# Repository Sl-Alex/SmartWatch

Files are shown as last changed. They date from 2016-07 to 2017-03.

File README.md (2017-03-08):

# General description
This project aims to create an open-source smartwatch with the following functionality:
- 1.3" OLED display (bright enough to work in outdoor conditions)
- BLE module (HM-10), pin-to-pin compatibility with well-known HC-06
- small vibration motor (SMS/Call notifications and so on)
- STM32F103CBT6 microcontroller.
- Big external SPI flash memory (M25P40), SW OTA update and a lot of images can be stored there.
- BMC150 accelerometer/compass (can recognize double tap on the screen).
- BMP180 barometer/thermometer (just because there is a plenty of space).
- 320mAh battery allowing up to 3 weeks standby time (with BLE active).
- PCB size: 37*25, complete assembled height should be about 10mm.
- 3D models for all parts are in my [KiCAD_libs](https://github.com/Sl-Alex/KiCAD_libs) repository, case will be available a bit later, so the whole project can be easily reproduced.

# Hardware
Both schematic and PCB were created with KiCAD. KiCAD project is located in the PCB subfolder. Project uses components from my [KiCAD_libs](https://github.com/Sl-Alex/KiCAD_libs) repository.<br />
**Status**: Finished. PCB is assembled, all HW features are tested and work as expected. Standby time seems to be about 3 weeks (with BLE active).

# Software
Project is created in [EmBitz](https://www.embitz.org/)<br />
**Status**: Can be used on a daily basis with some basic functionality (automatic date/time synchronization, SMS reception). Feel free to submit patches, create or discuss issues [here](https://github.com/Sl-Alex/SmartWatch/issues).<br />

# Licensing
The whole project is available under GPL v3 license (see [LICENSE](LICENSE) file), except of files, which clearly mention other license type in the file header.

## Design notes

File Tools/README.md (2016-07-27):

# Tools for image production
## Flash Packer
This tool packs resource files in a single binary file, which can be directly downloaded into the external SPI flash.
Here is an example set of files:
- 000.txt (FW update version, ASCII text representing FW revision, for example "150")
- 001.bin (FW update itself)
- 002_FONT_SMALL.txt (all symbols for the FONT_SMALL in UCS-2LE charset)
- 002_FONT_SMALL.pbm (single image containing all symbols from FONT_SMALL in the same order like in *.txt file). PBM P4 format is used. Image has white background and black pixels. First column contains one black pixel at the font baseline. First row contain black pixels between symbols.
- 003.pbm (Image in PBM P4 format)
All necessary attributes will be calculated automatically.

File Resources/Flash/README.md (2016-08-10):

# Firmware resources
This folder contains all resources, which can be used by the firmware.
all resources should have proper naming, like NNN*.(bin|pbm|txt)
For example, 000_version.bin or 001_update.bin
3-digit number is mandatory and should match to the numbers defined in SmHwStorageIndices enumeration
(sm_hw_storage.h). Numbering starts from 000, and it is not allowed to skip some numbers.
When all resources are created, you can run flash_packer and it will produce update.bin file in this folder.
This file can be written directly to external flash using BLE connection or manually via any SPI flash adapter.

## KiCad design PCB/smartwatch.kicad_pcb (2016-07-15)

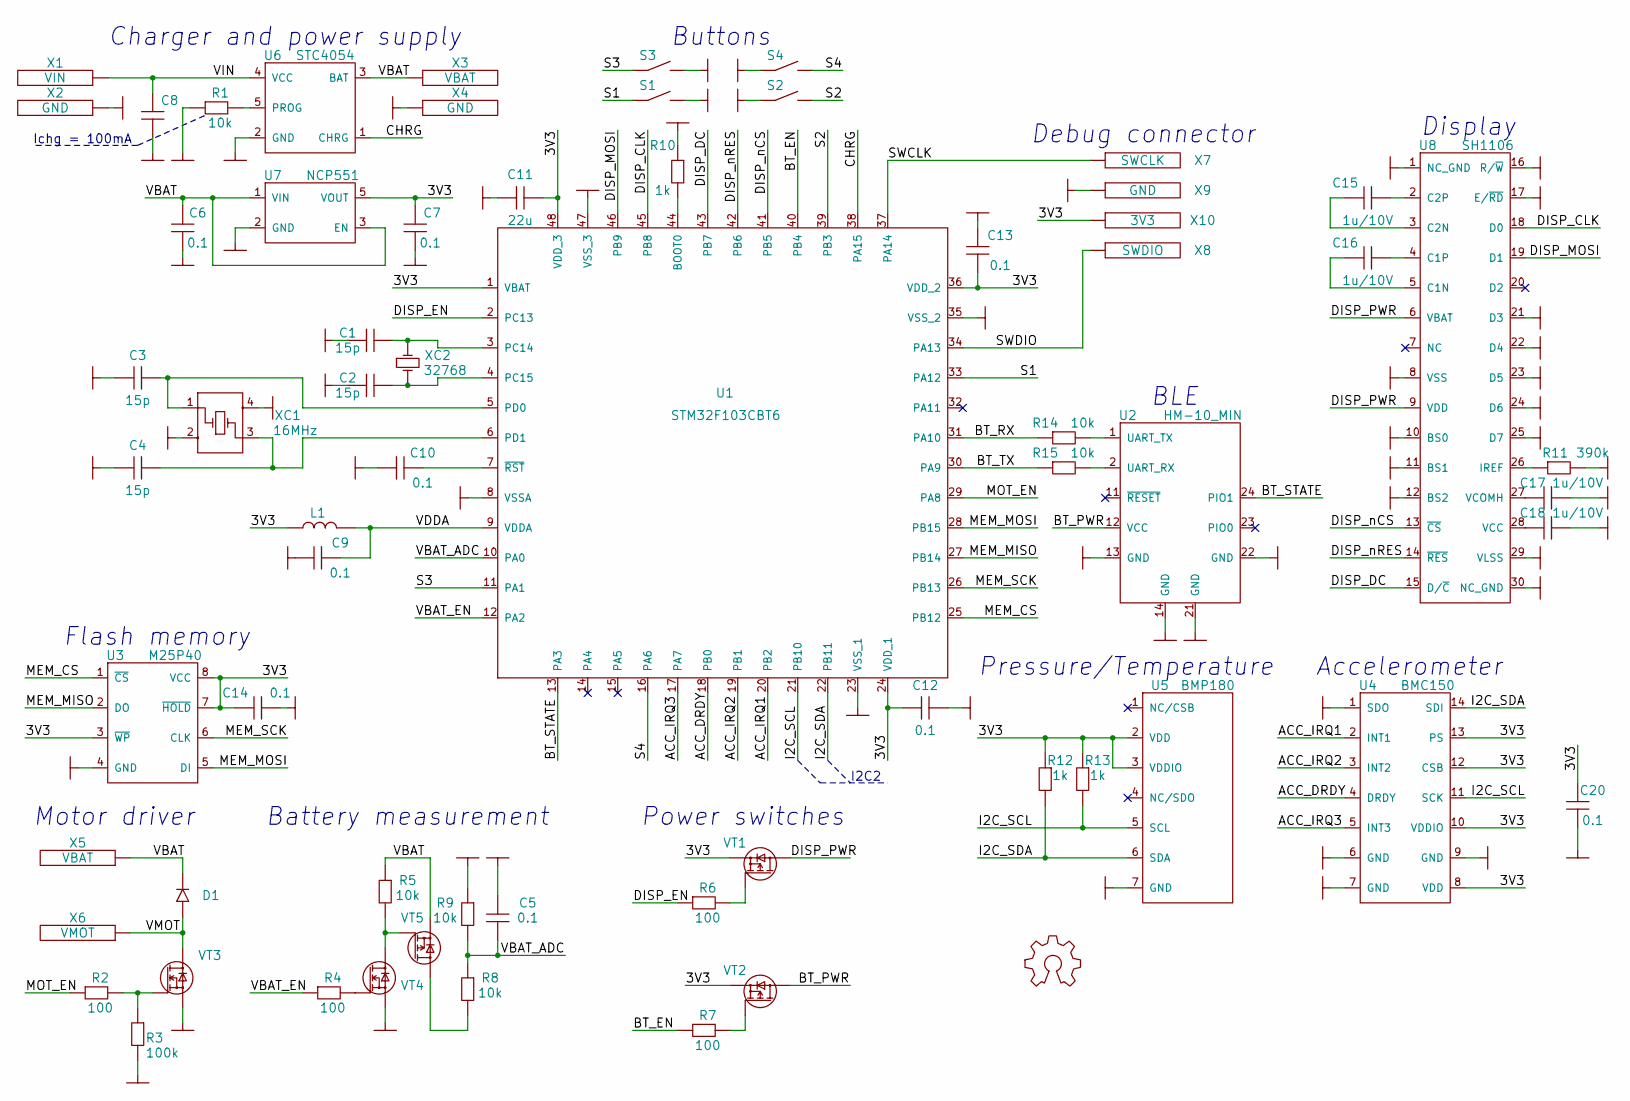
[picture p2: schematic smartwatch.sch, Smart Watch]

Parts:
C1, C2, C3, C4: 15p; 0402_C
C5, C6, C7, C9, C10, C12, C13, C14, C20: 0.1; 0402_C
C8: capacitor; 0402_C
C11: 22u; 0603_C
C15, C16, C17, C18: 1u/10V; 0603_C
D1: diode; SOD523
L1: inductor; 0603_L
LG?1: LOGO; OSHW
R1, R5, R8, R9, R14, R15: 10k; 0402_R
R2, R4, R6, R7: 100; 0402_R
R3: 100k; 0402_R
R10, R12, R13: 1k; 0402_R
R11: 390k; 0402_R
S1, S2, S3, S4: button_NO; B3U3000P
U1: STM32F103CBT6; LQFP48
U2: HM-10_MIN
U3: M25P40; SO8
U4: BMC150; LGA14
U5: BMP180; LGA7
U6: STC4054; SOT23-5
U7: NCP551; SOT23-5
U8: SH1106; UG-2864HSWEG01
VT1, VT2, VT5: MOSFET_P_DGS; PQFN2x2
VT3, VT4: MOSFET_N_DGS; PQFN2x2
X1: VIN; SLD_POINT
X2, X4, X9: GND; SLD_POINT
X3, X5: VBAT; SLD_POINT
X6: VMOT; SLD_POINT
X7: SWCLK; SLD_POINT
X8: SWDIO; SLD_POINT
X10: 3V3; SLD_POINT
XC1: 16MHz; SMD_3225
XC2: 32768; SMD_3215

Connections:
/3V3: C7.2, C11.1, C12.1, C13.1, C14.2, C20.2, L1.1, R12.1, R13.1, U1.1 (VBAT), U1.24 (VDD_1), U1.36 (VDD_2), U1.48 (VDD_3), U3.3 (~WP), U3.7 (~HOLD), U3.8 (VCC), U4.8 (VDD), U4.10 (VDDIO), U4.12 (CSB), U4.13 (PS), U5.2 (VDD), U5.3 (VDDIO), U7.5 (VOUT), VT1.3 (S), VT2.3 (S), X10.1
/ACC_DRDY: U1.18 (PB0), U4.4 (DRDY)
/ACC_IRQ1: U1.20 (PB2), U4.2 (INT1)
/ACC_IRQ2: U1.19 (PB1), U4.3 (INT2)
/ACC_IRQ3: U1.17 (PA7), U4.5 (INT3)
/BT_EN: R7.1, U1.40 (PB4)
/BT_PWR: U2.12 (VCC), VT2.1 (D)
/BT_RX: R14.1, U1.31 (PA10)
/BT_STATE: U1.13 (PA3), U2.24 (PIO1)
/BT_TX: R15.1, U1.30 (PA9)
/CHRG: U1.38 (PA15), U6.1 (CHRG)
/DISP_CLK: U1.45 (PB8), U8.18 (D0)
/DISP_DC: U1.43 (PB7), U8.15 (D/~C)
/DISP_EN: R6.1, U1.2 (PC13)
/DISP_MOSI: U1.46 (PB9), U8.19 (D1)
/DISP_PWR: U8.6 (VBAT), U8.9 (VDD), VT1.1 (D)
/DISP_nCS: U1.41 (PB5), U8.13 (~CS)
/DISP_nRES: U1.42 (PB6), U8.14 (~RES)
/I2C_SCL: R13.2, U1.21 (PB10), U4.11 (SCK), U5.5 (SCL)
/I2C_SDA: R12.2, U1.22 (PB11), U4.14 (SDI), U5.6 (SDA)
/MEM_CS: U1.25 (PB12), U3.1 (~CS)
/MEM_MISO: U1.27 (PB14), U3.2 (DO)
/MEM_MOSI: U1.28 (PB15), U3.5 (DI)
/MEM_SCK: U1.26 (PB13), U3.6 (CLK)
/MOT_EN: R2.1, U1.29 (PA8)
/S1: S1.1, U1.33 (PA12)
/S2: S2.2, U1.39 (PB3)
/S3: S3.1, U1.11 (PA1)
/S4: S4.2, U1.16 (PA6)
/SWCLK: U1.37 (PA14), X7.1
/SWDIO: U1.34 (PA13), X8.1
/VBAT: C6.1, D1.2, R5.1, U6.3 (BAT), U7.1 (VIN), U7.3 (EN), VT5.3 (S), X3.1, X5.1
/VBAT_ADC: C5.2, R8.1, R9.2, U1.10 (PA0)
/VBAT_EN: R4.1, U1.12 (PA2)
/VDDA: C9.2, L1.2, U1.9 (VDDA)
/VIN: C8.2, U6.4 (VCC), X1.1
/VMOT: D1.1, VT3.1 (D), X6.1
GND: C1.1, C2.1, C3.1, C4.1, C5.1, C6.2, C7.1, C8.1, C9.1, C10.1, C11.2, C12.2, C13.2, C14.1, C17.2, C18.2, C20.1, R1.1, R3.2, R9.1, R10.1, R11.2, S1.2, S2.1, S3.2, S4.1, U1.8 (VSSA), U1.23 (VSS_1), U1.35 (VSS_2), U1.47 (VSS_3), U2.13 (GND), U2.14 (GND), U2.21 (GND), U2.22 (GND), U3.4 (GND), U4.1 (SDO), U4.6 (GND), U4.7 (GND), U4.9 (GND), U5.7 (GND), U6.2 (GND), U7.2 (GND), U8.1 (NC_GND), U8.8 (VSS), U8.10 (BS0), U8.11 (BS1), U8.12 (BS2), U8.16 (R/~W), U8.17 (E/~RD), U8.21 (D3), U8.22 (D4), U8.23 (D5), U8.24 (D6), U8.25 (D7), U8.29 (VLSS), U8.30 (NC_GND), VT3.3 (S), VT4.3 (S), X2.1, X4.1, X9.1, XC1.2 (NC), XC1.4 (NC)
unnamed: C1.2, U1.3 (PC14), XC2.1
unnamed: C2.2, U1.4 (PC15), XC2.2
unnamed: C3.2, U1.5 (PD0), XC1.1
unnamed: C4.2, U1.6 (PD1), XC1.3
unnamed: C10.2, U1.7 (~RST)
unnamed: C15.1, U8.3 (C2N)
unnamed: C15.2, U8.2 (C2P)
unnamed: C16.1, U8.5 (C1N)
unnamed: C16.2, U8.4 (C1P)
unnamed: C17.1, U8.27 (VCOMH)
unnamed: C18.1, U8.28 (VCC)
unnamed: R1.2, U6.5 (PROG)
unnamed: R2.2, R3.1, VT3.2 (G)
unnamed: R4.2, VT4.2 (G)
unnamed: R5.2, VT4.1 (D), VT5.2 (G)
unnamed: R6.2, VT1.2 (G)
unnamed: R7.2, VT2.2 (G)
unnamed: R8.2, VT5.1 (D)
unnamed: R10.2, U1.44 (BOOT0)
unnamed: R11.1, U8.26 (IREF)
unnamed: R14.2, U2.1 (UART_TX)
unnamed: R15.2, U2.2 (UART_RX)

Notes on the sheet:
Motor driver
Battery measurement
Power switches
Pressure/Temperature
Accelerometer
BLE
Display
Flash memory
Charger and power supply
Buttons
Debug connector
Ichg = 100mA
I2C2

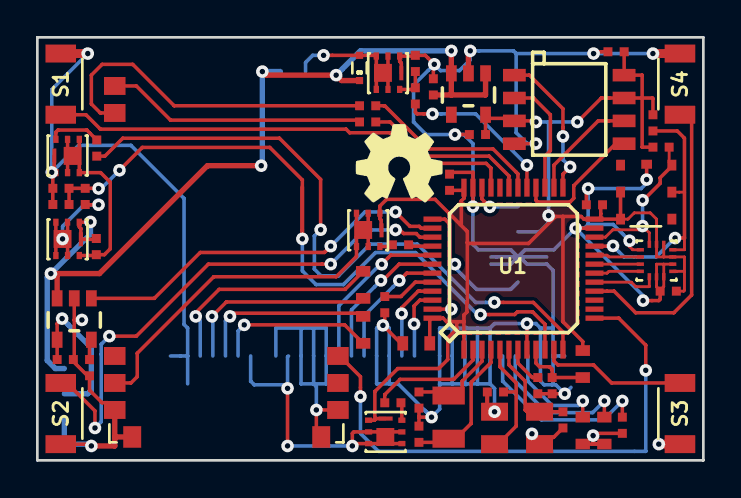
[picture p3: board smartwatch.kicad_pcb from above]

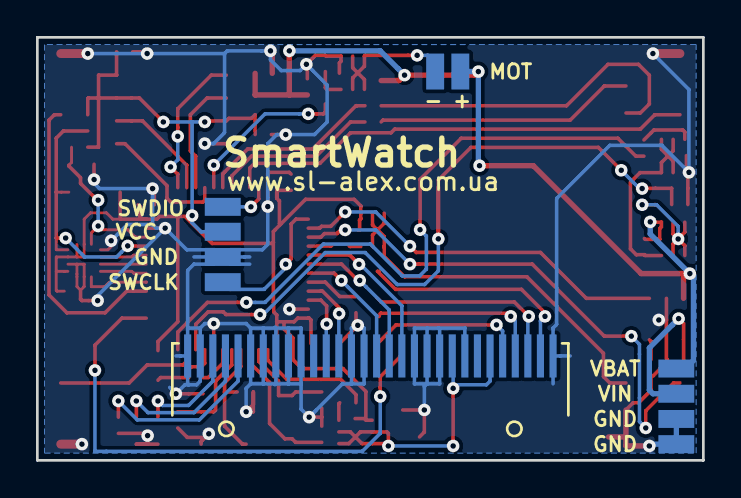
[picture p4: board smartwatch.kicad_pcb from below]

Board: 2 copper layers, 37.0 x 23.5 mm, 66 parts (11 on the bottom side), 60 nets.

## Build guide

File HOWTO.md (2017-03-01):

# Prerequisites
In order to make it work you should have:

1. ST-Link or other SWD programmer/debugger
2. Android Studio IDE
3. EmBitz IDE
4. Soldering equipment (you should be able to solder LGA-14 package, the rest is much easier)
5. USB-UART adapter with 3.3V IO levels
6. Qt Creator and development environment

SWD programmer/debugger will be required for FW flashing.

Android Studio will be required for Android SW compilation.

EmBitz will be required for FW compilation/debugging.

USB-UART adapter will be required for initial HM-10 configuration.

# How to make it work

You should do the following steps:

1. Resources compilation
2. HM-10 configuration
3. Device assembling
4. External SPI memory flashing
5. FW flashing
6. Android application building

Future versions will be much simpler, steps 3, 5 and 6 will be removed.

## 1. Resources compilation

All resources are in the [root]/Resources/Flash folder.
Open [root]Tools/flash_packer/flash_packer.pro with Qt Creator. Run it.
It will take all resources and pack them in a single update.bin file in resources folder.

## 2. HM-10 configuration

The only strict requirement is a UART bitrate, which should be set to 115200.
See HM-10 documentation for details.

## 3. Device assembling

The hardest part of the assembling is the installation of the accelerometer, which comes in a LGA-14 case.
It is recommended to assemble everything in the following order:

1. Solder everything except of: BMP180, HM-10, buttons, display, battery.
2. Connect ST-Link to the debug pads on the bottom of the board.
3. Compile and flash the firmware (EmBitz project is in [root]/FW/ folder).
4. Run the FW in debug mode and ensure that BMC150 issues acknowledges on both I<sup>2</sup>C addresses.
5. Solder the rest.
6. Connect 5V power supply to the VIN pad on the bottom of the PCB
7. Check that battery charge works fine.

## 4. External SPI memory flashing

If you have an SPI flash programmer you can just flash update.bin to the external memory
(STM32 must be in reset state or without any FW).
If you don't have it do the following:

1. Open sm_hw_storage.cpp, find the line containing #include "update.inc", uncomment it.
2. Uncomment lines with "eraseBulk()" and "writeBuffer(update_bin, 0, update_bin_len)"
3. Convert update.bin to update.inc using xxd: "xxd -i update.bin update.inc"
4. Put update.inc in [root]/FW/inc folder
5. Build and run this FW.
6. Wait a bit while external flash is being flashed
7. Comment lines from step 1 and 2.

## 5. FW flashing

If external memory is already flashed and update-related lines are commented then just build and run the FW in "Release" mode.

## 6. Android application building

Open Android project in the [root]SW/SmCenter folder.
Open SW/SmCenter/app/src/main/java/ua/com/slalex/smcenter/services/SmWatchService.java,
find a line containing "setBtAddress" and change the address to the address of your HM-10 module.
Now everything is ready, just build and run the SW.

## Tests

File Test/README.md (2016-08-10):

# Tools for testing
This folder contains various test software. Each test project is located in its own subfolder. Here is a short description of all subfolders.

##gui_test
This project performs various tests of the implemented GUI subsystem. Requires QT. Emulates external flash using update.bin file. Can be used for GUI testing and development directly on PC (without microcontroller).

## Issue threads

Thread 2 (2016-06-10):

Finalize PCB

Sl-Alex, 2016-06-10:
All components should have correct values

Closed 2016-06-13.

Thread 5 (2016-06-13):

Create I²C HAL wrapper class

Sl-Alex, 2016-06-13:
Will be useful for both accelerometer/magnetometer and barometer/thermometer. Source code from my GPS clock can be taken as a basis, it seems to be good enough.

Sl-Alex, 2016-07-28:
Draft code is done, accelerometer works fine.

Closed 2016-07-28.

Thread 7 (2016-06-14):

Implement power manager

Sl-Alex, 2016-06-14:
SmHwPowerMgr class should be responsible for the sleep/wake procedure and for the proper notifications.

Sl-Alex, 2016-06-14:
All classes, which need power management support, should be able to subscribe to the SmHwPowerMgr events.

Sl-Alex, 2016-06-14:
STOP mode should be used, because we have to keep RAM and peripheral configuration. In STOP mode we can still wake from EXTI events/interrupts.

Closed 2016-06-14.

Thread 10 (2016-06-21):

MCU replacement

Sl-Alex, 2016-06-21:
It would be nice to replace STM32F103C8T6 with STM32F103CBT6, becase it has 128kB of flash instead of 64kB. It is a good idea because this flash memory will be occupied not only by the main application, but also by the bootloader, which will update the application. These two chips seems to be pin-to-pin compatible.

Closed 2016-07-15.

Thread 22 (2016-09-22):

Enhance SmHwBattery charge status

Sl-Alex, 2016-09-22:
Check it with a real HW and implement three charge states:
1. Discharging (charge status pin is float)
2. Charging (charge status pin is open-drain low)
3. Charged (power supply is still connected, 20μA pull-down on the charge status pin)

Closed 2016-10-03.

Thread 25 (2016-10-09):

Finalize sleep mode implementation

Sl-Alex, 2016-10-09:
Device should not enable display on each wakeup event.
Automatic sleep management should be implemented (for example 10 seconds timeout in case of display is active, 2 seconds otherwise). It seems to be possible to implement it in SmHwPowerMgr.
By default device should be in a sleep mode as long as it is possible.

Sl-Alex, 2016-10-26:
Seems to work now (battery life is more than 2 weeks with BLE active).
TODO: Display should be kept disabled after wakeup. Display should be enabled only on key press (other conditions are to be defined later).

Closed 2016-10-29.

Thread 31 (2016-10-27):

Define BT communication protocol

Sl-Alex, 2016-10-27:
BT module works as a transparent UART, but BLE packet is about 20 bytes long.
It would be fine to define UART protocol which works with 20-byte packets.

Sl-Alex, 2016-11-18:
Verified, 20 bytes is a maximum. I would like to use only a full-length packets in order to simplify UART receive procedure (in this case it can be done via DMA with timeout).

Sl-Alex, 2016-11-18:
BTW, it seems to be impossible to use PIN/PASS on HM-10 in Android (at least on Android 6), so encryption should be done by software.

Closed 2016-11-24.

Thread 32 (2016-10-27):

Implement bootloader

Sl-Alex, 2016-10-27:
Bootloader should have following features:
1. Erase/write SPI storage
2. Work with BT (e.g. receive updates)
3. Update the SW
4. Show update progress on the display (at least as a progress bar, but a simple ASCII font and some diagnistic messages are also nice to have)

Reusage of CPP classes from the main application is highly recommended.

Sl-Alex, 2017-03-02:
Let's limit the size of the bootloader to 20K. Application will get the rest.
Update procedure (draft, but seems to be fine):

1.  Application switches to bootloader by writing something special to one of RTC BKP registers and reboots.
2. Bootloader clears RTC BKP register, receives update.bin and writes it to the external SPI flash, shows receive progress and a kind of a "receiving update" message.
3. Bootloader updates the FW, shows update progress and a kind of an "updating FW" message.
4. Bootloader starts updated FW.

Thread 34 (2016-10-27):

Android software (draft)

Sl-Alex, 2016-10-27:
Following features must be implemented:
1. BLE scanner and device selection (can be implemented later)
2. Date/Time sync
3. FW version request

Sl-Alex, 2016-12-05:
SW structure should be like this:

Main window should:
1. Show device status if connected
	- Battery
	- Signal strength
	- FW version and other info
2. Show "Connect" button if SmartWatch device is not known yet

Settings window should have:
1. Date/time synchronization switch (On/Off)
2. Notifications switch (On/Off)
3. Notifications filter (on-off switch, notifications filter window on press)
4. Connect status / connect to a new device

Notifications filter window should have:
1. Filter type: (black-list / white-list)
2. List content (regular expressions should be supported):
TODO - define later

Log window:
Type:
	Connection
	Date/Time
	Log message

Sl-Alex, 2017-02-28:
Closed in rev. 152

Closed 2017-02-28.

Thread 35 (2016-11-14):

Power management bug

Sl-Alex, 2016-11-14:
CPU does not switch to sleep mode after some menu navigation.

Closed 2016-11-19.

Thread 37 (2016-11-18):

Extend onWake

Sl-Alex, 2016-11-18:
Implement wakeup event information in a form of a bitmask (8 bits seems to be enough).
Display should be powered on only in case of a keyboard or an accelerometer event.

Closed 2016-11-19.

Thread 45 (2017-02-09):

Implement BT UART reception/transmission on STM32

Sl-Alex, 2017-02-09:
STM32 must:
 - receive packets using interrupts and timeouts.
 - transmit packets using DMA.

Sl-Alex, 2017-02-23:
Implemented

Closed 2017-02-23.

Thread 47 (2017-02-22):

Implement sleep mode for emulator

Sl-Alex, 2017-02-22:
It would be nice to use at least some limited functionality of the power manager in emulator.

Sl-Alex, 2017-02-23:
Rejecting, it requires too much changes.

Closed 2017-02-23.

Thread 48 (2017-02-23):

Implement notifications in SmHwMotor class

Sl-Alex, 2017-02-23:
It would be nice to have a possibility to start and stop SmHwMotor notifications:
`void SmHwMotor::getInstance()->startNotification(uint32_t slots, uint8_t length);`
`void SmHwMotor::getInstance()->stopNotification(void);`

`slots` defines up to 32 time slots (0 means short, 1 means long), so 0b1011 means (LSB to MSB):
long-long-short-long
Motor is on during odd slot and off during even slot.
`length` defines number of slots to use.

`stopNotification` just cancels ongoing notification (if any) and stops motor.

Closed 2017-02-28.

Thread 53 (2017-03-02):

User should be able to select a correct BLE device on Android side

Sl-Alex, 2017-03-02:
It would be nice to properly implement such a feature.
There is a "Bind a new device" button, it should start a scan and suggest all nearby BLE devices.
Users choice should be stored in the application preferences and SmWatchService should be restarted with a new device address.

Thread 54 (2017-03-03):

SmWatchService dies

Sl-Alex, 2017-03-03:
It seems that in some cases (low memory?) Android kills our SmWatchService. Of course, in this case all messages will remain undelivered. It would be fine to use setForeground and display a notification. This notification can also show some service statistics and service status.

Sl-Alex, 2017-03-04:
Commit c4ebd31 should fix it. Will check.

Sl-Alex, 2017-03-08:
Not fixed, reopening.

Sl-Alex, 2017-03-08:
In case BLE connection fails, disconnect and close should be anyway called.

Closed 2017-03-08.

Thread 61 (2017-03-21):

SmCenter failure

Sl-Alex, 2017-03-21:
When device is not available, the following error can occur:

E AndroidRuntime: java.lang.NullPointerException: Attempt to invoke virtual method 'void android.bluetooth.BluetoothGatt.disconnect()' on a null object reference
E AndroidRuntime: 	at ua.com.slalex.smcenter.BLE.BleDevice.disconnect(BleDevice.java:210)
E AndroidRuntime: 	at ua.com.slalex.smcenter.BLE.BleDevice.connect(BleDevice.java:182)
E AndroidRuntime: 	at ua.com.slalex.smcenter.BLE.BleThread.run(BleThread.java:60)

Closed 2017-03-21.

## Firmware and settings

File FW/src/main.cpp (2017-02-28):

/*
**
**                           Main.c
**
**
**********************************************************************/
/*
   Last committed:     $Revision: 00 $
   Last changed by:    $Author: $
   Last changed date:  $Date:  $
   ID:                 $Id:  $

**********************************************************************/
//#include "stm32f10x_conf.h"
#include "sm_display.h"
#include "sm_hal_gpio.h"
#include "sm_hal_spi_sw.h"
#include "sm_hal_spi_hw.h"
#include "sm_hal_rcc.h"
#include "sm_hal_rtc.h"

#include "sm_hw_keyboard.h"
#include "sm_hw_motor.h"
#include "sm_hw_battery.h"
#include "sm_hw_bt.h"
#include "sm_hw_storage.h"
#include "sm_hw_powermgr.h"
#include "sm_hw_bmc150.h"
#include "sm_hw_bmp180.h"

#include "sm_desktop.h"
#include "sm_canvas.h"
#include "sm_image.h"
#include "sm_font.h"
#include "sm_animator.h"

#define I2C_ACC 0x10
#define I2C_MAGN 0x12

int main(void)
{
    SystemCoreClockUpdate();
    SmHalRcc::updateClocks();

    SmHalRcc::clockEnable(RCC_PERIPH_SPI2);
    SmHalRcc::clockEnable(RCC_PERIPH_GPIOA);
    SmHalRcc::clockEnable(RCC_PERIPH_GPIOB);
    SmHalRcc::clockEnable(RCC_PERIPH_GPIOC);
    SmHalRcc::clockEnable(RCC_PERIPH_AFIO);
    SmHalRcc::clockEnable(RCC_PERIPH_ADC1);
    SmHalRcc::clockEnable(RCC_PERIPH_I2C2);

    SmHwBmc150::getInstance()->init();
    SmHwBmp180::getInstance()->init(); /// I2C init is done in BMC150 initialization

    // Disable JTAG, SWD remains enabled
    // This is for PA15, which is JTDI by default
    AFIO->MAPR|=AFIO_MAPR_SWJ_CFG_JTAGDISABLE;

    // Initialize system timer (10 clients, 1ms resolution)
    SmHalSysTimer::initSubscribersPool(10);
    // Initialize with 1ms resolution
    SmHalSysTimer::init(1);
    // Initialize power manager (10 clients)
    SmHwPowerMgr::getInstance()->initSubscribersPool(10);
    // Initialize wake lines
    SmHwPowerMgr::getInstance()->init();

    SmHwBt::getInstance()->init();


    SmHwBattery::getInstance()->init();

    SmHwMotor * motor = new SmHwMotor();

    SmHwStorage::getInstance()->init();

    // Initialize display
    SmDisplay * display = SmDisplay::getInstance();
    display->init(128,64);
    display->getCanvas()->clear();
    display->powerOn();
    display->update();

    SmHalI2c::getInstance()->reset(false);

    uint8_t data = 1;
    uint8_t reg[2] = {0x4b, 0x01};

    SmHalI2c::getInstance()->transfer(I2C_MAGN, &reg[0], 2, 0, 0);

    reg[0] = 0x40;
    // 0b00110010;
    SmHalI2c::getInstance()->transfer(I2C_MAGN, &reg[0], 1, &data, 1);

    SmHwBmc150::getInstance()->checkPresent();
    SmHwBmp180::getInstance()->checkPresent();

    SmDesktop::getInstance()->init();
    while (1)
    {
        SmHalSysTimer::processEvents();
        display->update();
        SmHwBt::getInstance()->update();
        if (SmHwBt::getInstance()->isNotification())
        {
            display->powerOn();
            SmNotification * pNotification = SmDesktop::getInstance()->getNotification();

            if (pNotification)
                pNotification->addCount();
            else
                SmDesktop::getInstance()->showNotification();

            // Show "SOS" pattern (...---...)
            motor->startNotification(0x0FC0,9);
            SmHwBt::getInstance()->clearNotification();
        }
        SmHwPowerMgr::getInstance()->updateState();
    }
}

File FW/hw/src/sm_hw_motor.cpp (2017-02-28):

#include "sm_hw_motor.h"

#include "sm_hal_gpio.h"

#define MOTOR_PORT  GPIOA_BASE
#define MOTOR_PIN   8

/// "Tick" of the motor, ms
#define MOTOR_TICK  80

#define SHORT_SLOT  MOTOR_TICK
#define LONG_SLOT   MOTOR_TICK*3

SmHwMotor::SmHwMotor()
{
    mGpio = new SmHalGpio<MOTOR_PORT, MOTOR_PIN>();
    mGpio->setModeSpeed(SM_HAL_GPIO_MODE_OUT_PP, SM_HAL_GPIO_SPEED_2M);
    mPattern = 0;
    mLength = 0;
    SmHwPowerMgr::getInstance()->subscribe(this);
    disable();
}

void SmHwMotor::onSleep(void)
{
    disable();
}

void SmHwMotor::onWake(uint32_t wakeSource)
{
}

void SmHwMotor::onTimer(uint32_t timeStamp)
{
    if (mPattern & 1)
        SmHalSysTimer::subscribe(this, LONG_SLOT, false);
    else
        SmHalSysTimer::subscribe(this, SHORT_SLOT, false);

    if (mLength & 1)
        enable();
    else
        disable();


    mPattern >>= 1;

    if (mLength)
        mLength--;
    else
        stopNotification();
}

void SmHwMotor::startNotification(uint32_t pattern, uint8_t pulses)
{
    if ((pulses == 0) || (pulses > 16))
        return;

    mPattern = pattern;
    mLength = pulses * 2 - 1;

    // Call onTimer with any value
    onTimer(0);
}

void SmHwMotor::stopNotification(void)
{
    SmHalSysTimer::unsubscribe(this);
	disable();
}

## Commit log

2016-04-11 Draft PCB is added
    [smartwatch.kicad_pcb, smartwatch.sch]
2016-04-20 First iteration (only SH1106 and some GUI classes work fine)
    [smartwatch.kicad_pcb, smartwatch.sch]
2016-04-21 SPI Flash nWR is connected to 3V3
    [smartwatch.kicad_pcb, smartwatch.sch]
2016-04-21 SPI flash initial support (yet TBD) GUI improvements
2016-05-03 PCB (everything is done, should be checked)
    [smartwatch.kicad_pcb, smartwatch.sch]
2016-05-03 PCB: Preparing production files
    [smartwatch-B.Cu.gbl, smartwatch-B.Mask.gbs, smartwatch-B.SilkS.gbo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]
2016-05-04 Minor update and final production files for seeedstudio.
    [smartwatch-B.SilkS.gbo, smartwatch.GBL, smartwatch.GBO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]
2016-06-04 Values update
    [smartwatch.kicad_pcb, smartwatch.sch]
2016-06-08 GPIO class, draft SW SPI and display classes
    [smartwatch.sch]
2016-06-08 PCB component values update
    [smartwatch.kicad_pcb, smartwatch.sch]
2016-06-09 HW SPI class (templated, based on SmHwAbstractSpi)
2016-06-09 HW SPI enable. RCC will be implemented in a separate class.
2016-06-09 RCC clocking control, display power control
2016-06-09 Bugfixes (wrong pointer, wrong loop iterator)
    [sm_display.cpp]
2016-06-09 HW and SW SPI bugfixes
    [main.cpp]
2016-06-10 SmHwSysTimer first prototype
2016-06-12 This closes #1 (system timer)
    [smartwatch.sch]
2016-06-12 Buttons draft
2016-06-12 Removing old display and GPIO drivers
2016-06-12 Battery measurement draft
2016-06-13 Removing obsolete SmartStorage, it will be replaced by SmHwStorage class (see #3)
    [sm_display.cpp]
2016-06-13 Closes #2 (all values are mentioned)
    [smartwatch.sch]
2016-06-14 Power manager skeleton, will be implemented in the next commits. See #7
2016-06-14 This closes #7 (power manager)
2016-06-15 This closes #8 (keyboard is implemented instead of separate buttons)
2016-06-16 Adding missing keyboard files
    [sm_hw_keyboard.cpp]
2016-06-16 ADC and SPI flash power management implementation, SmHalSysTimer bugfix
    [main.cpp, sm_hw_battery.cpp, sm_hw_storage.cpp]
2016-07-15 Closes #10 (migration to 128kB flash)
    [smartwatch.kicad_pcb, smartwatch.sch]
2016-07-27 Flash packer: get correct file list
    [main.cpp]
2016-07-28 Solving I2C reinitializing issue.
    [main.cpp, sm_hal_i2c.cpp]
2016-07-30 This closes #12. Minor code style fixes.
    [main.cpp, sm_hal_abstract_spi.h]
2016-08-05 This closes #13 (Printing strings with SmFont)
2016-08-10 Keyboard and system timer can be emulated in QT test software
2016-08-20 Flash packer bug fix, schematic update, complete Ukrainian letters support
    [smartwatch.sch]
2016-09-21 Adding charge icons, removing update.bin
2016-09-21 Battery enhancement
2016-09-22 Charge status and battery icons on the desktop
2016-10-02 Updates for #22 (Charge status) and #20 (RTC wrapper).
2016-10-03 This closes #22 (charge status)
2016-10-21 SmMainMenu draft (with animation), SmAnimator bugfixes and improvements, many minor improvements
    [main.cpp]
2016-10-27 This closes #29 (power on and off symbols). This closes #28 (editors). This updates #16 (menus).
2016-11-19 This closes #35 (power management bug), closes #37 (extend onWake)
    [main.cpp, sm_display.cpp]
2016-11-20 RTC alarm bugfix, emulator update
    [main.cpp, sm_display.cpp, sm_hw_powermgr.cpp]
2016-12-04 First early draft Android app (does not work at all)
    [app_bar_main.xml]
2016-12-06 Menu layout
    [app_bar_main.xml]
2016-12-07 Update for #34 (Android software) Draft fragments are implemented, fragment switching works.
2016-12-11 Extendind SmCenter template (#34)
    [app_bar_main.xml]
2017-02-09 BT UART DMA send implementation
2017-03-01 Fix compile error on Windows
    [main.cpp]
2017-03-05 Extended timeout for notifications, asking for permissions, adding missing files.
    [sm_hw_powermgr.h]
2017-03-06 This closes #51 (version string is loadable from external flash). Minor stability improvements
    [sm_hw_bt.cpp]
2017-03-12 This closes #58 (battery measurement)
